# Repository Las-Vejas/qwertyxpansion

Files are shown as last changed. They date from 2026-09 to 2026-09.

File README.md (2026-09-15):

# qwertyxpansion

This is a keyboard for the [Hackxpansion console](https://github.com/hackclub/hackxpansion). It features a qwerty keyboard, with 4 modifier keys and an LED. The switches are SPST.

I will be making the 3d case later on, as it's very hard to make correctly without the actual PCB.

## Images
|||
|---|---|
|||

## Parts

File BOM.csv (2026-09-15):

Reference | Price | Price | Value | LCSC Part #
D1,D2,D3,D4,D5,D6,D7,D8,D9,D10,D11,D12,D13,D14,D15,D16,D17,D18,D19,D20,D21,D22,D23,D24,D25,D26,D27,D28,D29,D30,D31,D32,D33 | 1.44 $US | 33 | D_Small | C28646371
D34 | 0.69 $US | 1 | LED | C20608782
J1,J2 | 0.00 $US | 2
R1 | 0.19 $US | 1 | 75K | C2909383
R2 | 0.15 $US | 1 | 1K | C140197
R3 | 0.21 $US | 1 | 300 | C25102
SW1,SW2,SW3,SW4,SW5,SW6,SW7,SW8,SW9,SW10,SW11,SW12,SW13,SW14,SW15,SW16,SW17,SW18,SW19,SW20,SW21,SW22,SW23,SW24,SW25,SW26,SW27,SW28,SW29,SW30,SW31,SW32,SW33 | 2.02 $US | 33 | SW_Push_45deg | C720477
PCB | 4.00 $US | 5
Stencil | 3.07 $US | 1
TOTAL | 11.77 $US

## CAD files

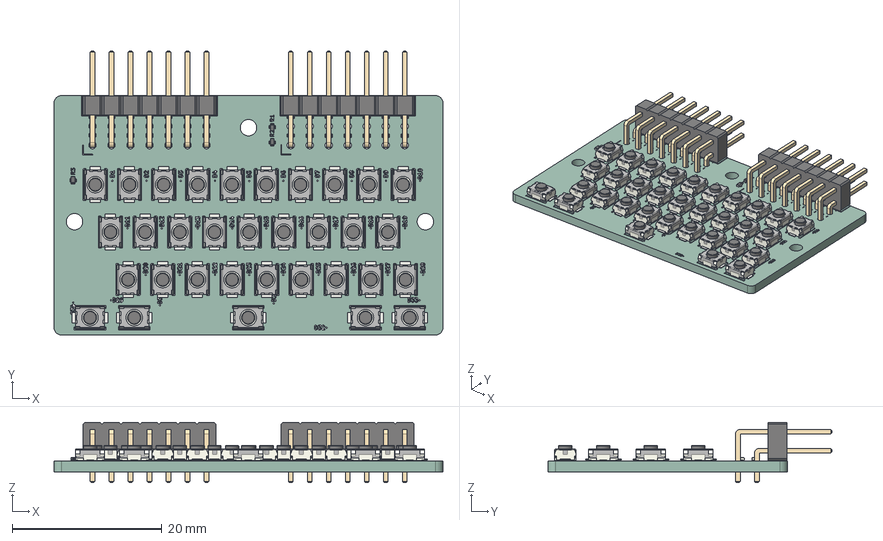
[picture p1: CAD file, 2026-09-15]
3d/qwertyxpansionPCB.step
52.0 x 38.0 x 8.08 mm
SW_Push_SPST_NO_Alps_SKRK x 33
R_0402_1005Metric x 3
PinHeader_2x07_P254mm_Horizontal x 2
keeb_silkscreen x 2
keeb_PCB

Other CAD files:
3d/qwertyxpansionCASE.f3z

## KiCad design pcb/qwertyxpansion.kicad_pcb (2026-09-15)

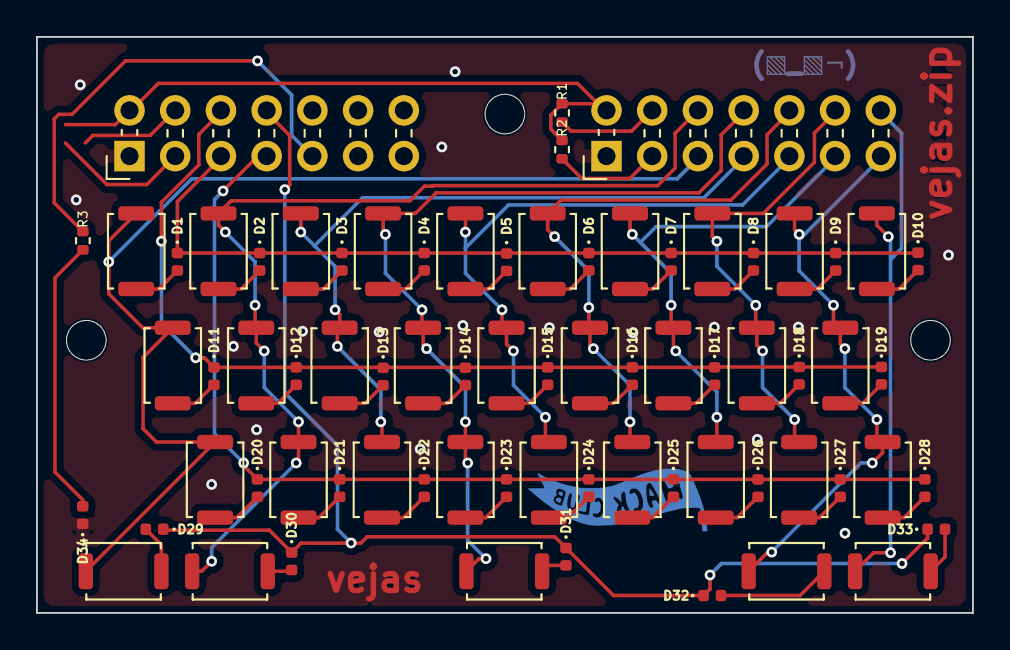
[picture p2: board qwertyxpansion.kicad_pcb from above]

Board: 2 copper layers, 52.0 x 32.0 mm, 72 parts (0 on the bottom side), 53 nets.

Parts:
D1, D2, D3, D4, D5, D6, D7, D8, D9, D10, D11, D12, D13, D14, D15, D16, D17, D18, D19, D20, D21, D22, D23, D24, D25, D26, D27, D28, D29, D30, D31, D32, D33: D_Small; D_0402_1005Metric
D34: LED; D_0402_1005Metric
J1, J2: PinHeader_2x07_P2.54mm_Horizontal
R1: 75K; R_0402_1005Metric
R2: 1K; R_0402_1005Metric
R3: 300; R_0402_1005Metric
SW1: Q; SW_Push_SPST_NO_Alps_SKRK
SW2: W; SW_Push_SPST_NO_Alps_SKRK
SW3: E; SW_Push_SPST_NO_Alps_SKRK
SW4: R; SW_Push_SPST_NO_Alps_SKRK
SW5: T; SW_Push_SPST_NO_Alps_SKRK
SW6: Y; SW_Push_SPST_NO_Alps_SKRK
SW7: U; SW_Push_SPST_NO_Alps_SKRK
SW8: I; SW_Push_SPST_NO_Alps_SKRK
SW9: O; SW_Push_SPST_NO_Alps_SKRK
SW10: P; SW_Push_SPST_NO_Alps_SKRK
SW11: A; SW_Push_SPST_NO_Alps_SKRK
SW12: S; SW_Push_SPST_NO_Alps_SKRK
SW13: D; SW_Push_SPST_NO_Alps_SKRK
SW14: F; SW_Push_SPST_NO_Alps_SKRK
SW15: G; SW_Push_SPST_NO_Alps_SKRK
SW16: H; SW_Push_SPST_NO_Alps_SKRK
SW17: J; SW_Push_SPST_NO_Alps_SKRK
SW18: K; SW_Push_SPST_NO_Alps_SKRK
SW19: L; SW_Push_SPST_NO_Alps_SKRK
SW20: Z; SW_Push_SPST_NO_Alps_SKRK
SW21: X; SW_Push_SPST_NO_Alps_SKRK
SW22: C; SW_Push_SPST_NO_Alps_SKRK
SW23: V; SW_Push_SPST_NO_Alps_SKRK
SW24: B; SW_Push_SPST_NO_Alps_SKRK
SW25: N; SW_Push_SPST_NO_Alps_SKRK
SW26: M; SW_Push_SPST_NO_Alps_SKRK
SW27: ,; SW_Push_SPST_NO_Alps_SKRK
SW28: .; SW_Push_SPST_NO_Alps_SKRK
SW29, SW30, SW31, SW32, SW33: SW_Push_45deg; SW_Push_SPST_NO_Alps_SKRK

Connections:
+3V3: J1.2 (3V3), J2.2 (3V3), R1.1, R2.1
/COL1: J1.5 (GPIO0), SW1.1, SW11.1, SW20.1, SW29.1
/COL2: J1.6 (GPIO1), SW2.1, SW12.1, SW21.1, SW30.1
/COL3: J1.7 (GPI02), SW3.1, SW13.1, SW22.1
/COL4: J1.8 (GPIO3), SW4.1, SW14.1, SW23.1, SW31.1
/COL5: J1.9 (GPIO4), SW5.1, SW15.1, SW24.1
/COL6: J1.10 (GPIO5), SW6.1, SW16.1, SW25.1
/COL7: J1.11 (GPIO6), SW7.1, SW17.1, SW26.1
/COL8: J1.12 (GPIO7), SW8.1, SW18.1, SW27.1
/COL9: J1.13 (GPIO8), SW9.1, SW19.1, SW28.1, SW32.1
/COL10: J1.14 (GPIO9), SW10.1, SW33.1
/ROW1: D1.1 (K), D2.1 (K), D3.1 (K), D4.1 (K), D5.1 (K), D6.1 (K), D7.1 (K), D8.1 (K), D9.1 (K), D10.1 (K), J2.5 (GPIO0)
/ROW2: D11.1 (K), D12.1 (K), D13.1 (K), D14.1 (K), D15.1 (K), D16.1 (K), D17.1 (K), D18.1 (K), D19.1 (K), J2.6 (GPIO1)
/ROW3: D20.1 (K), D21.1 (K), D22.1 (K), D23.1 (K), D24.1 (K), D25.1 (K), D26.1 (K), D27.1 (K), D28.1 (K), J2.7 (GPI02)
/ROW4: D29.1 (K), D30.1 (K), D31.1 (K), D32.1 (K), D33.1 (K), J2.8 (GPIO3)
GND: D34.1 (K), J1.1 (GND), J2.1 (GND)
unnamed: D1.2 (A), SW1.2
unnamed: D2.2 (A), SW2.2
unnamed: D3.2 (A), SW3.2
unnamed: D4.2 (A), SW4.2
unnamed: D5.2 (A), SW5.2
unnamed: D6.2 (A), SW6.2
unnamed: D7.2 (A), SW7.2
unnamed: D8.2 (A), SW8.2
unnamed: D9.2 (A), SW9.2
unnamed: D10.2 (A), SW10.2
unnamed: D11.2 (A), SW11.2
unnamed: D12.2 (A), SW12.2
unnamed: D13.2 (A), SW13.2
unnamed: D14.2 (A), SW14.2
unnamed: D15.2 (A), SW15.2
unnamed: D16.2 (A), SW16.2
unnamed: D17.2 (A), SW17.2
unnamed: D18.2 (A), SW18.2
unnamed: D19.2 (A), SW19.2
unnamed: D20.2 (A), SW20.2
unnamed: D21.2 (A), SW21.2
unnamed: D22.2 (A), SW22.2
unnamed: D23.2 (A), SW23.2
unnamed: D24.2 (A), SW24.2
unnamed: D25.2 (A), SW25.2
unnamed: D26.2 (A), SW26.2
unnamed: D27.2 (A), SW27.2
unnamed: D28.2 (A), SW28.2
unnamed: D29.2 (A), SW29.2
unnamed: D30.2 (A), SW30.2
unnamed: D31.2 (A), SW31.2
unnamed: D32.2 (A), SW32.2
unnamed: D33.2 (A), SW33.2
unnamed: D34.2 (A), R3.2
unnamed: J1.3 (MD0), R2.2
unnamed: J1.4 (MD1), R1.2
unnamed: J2.9 (GPIO4), R3.1

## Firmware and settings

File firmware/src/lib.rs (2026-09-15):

#![no_std]

extern crate alloc;

use alloc::boxed::Box;
use core::future::Future;
use core::pin::Pin;

use xpanse_api::{
    bus::allocator::BusAllocator,
    driver::{DriverError, DriverMeta, DualSlotDriver},
    gpio_bank::{BankPins, GpioBank},
    interfaces::leds::{Generic, pin_led},
    metadata::{ModuleDetectResistor, ModuleID, ModuleSlot},
    registry::Registry,
    reexports::{
        embassy_futures::select::select_array,
        embassy_rp::{
            Peri,
            gpio::{AnyPin, Input, Level, Output, Pull},
        },
        embassy_time::Timer,
    },
};

/// ROW1..ROW4, on GPIO0..GPIO3 of the left connector (J2).
const ROWS: usize = 4;
/// COL1..COL10, on GPIO0..GPIO9 of the right connector (J1).
const COLS: usize = 10;

/// Time for a column to follow its row after the row is switched.
const SETTLE_US: u64 = 10;
const SCAN_INTERVAL_MS: u64 = 1;
/// A matrix change is accepted once it reads the same for this many scans.
const DEBOUNCE_SCANS: u32 = 5;

/// A physical key on the module.
#[derive(Debug, Clone, Copy, PartialEq, Eq)]
pub enum Key {
    Q,
    W,
    E,
    R,
    T,
    Y,
    U,
    I,
    O,
    P,
    A,
    S,
    D,
    F,
    G,
    H,
    J,
    K,
    L,
    Z,
    X,
    C,
    V,
    B,
    N,
    M,
    Comma,
    Period,
    Space,
    /// Bottom row, far left (SW29).
    Mod1,
    /// Bottom row, left of the space bar (SW30).
    Mod2,
    /// Bottom row, right of the space bar (SW32).
    Mod3,
    /// Bottom row, far right (SW33).
    Mod4,
}

impl Key {
    /// The character the key types without modifiers, or `None` for modifiers.
    pub const fn as_char(self) -> Option<char> {
        Some(match self {
            Key::Q => 'q',
            Key::W => 'w',
            Key::E => 'e',
            Key::R => 'r',
            Key::T => 't',
            Key::Y => 'y',
            Key::U => 'u',
            Key::I => 'i',
            Key::O => 'o',
            Key::P => 'p',
            Key::A => 'a',
            Key::S => 's',
            Key::D => 'd',
            Key::F => 'f',
            Key::G => 'g',
            Key::H => 'h',
            Key::J => 'j',
            Key::K => 'k',
            Key::L => 'l',
            Key::Z => 'z',
            Key::X => 'x',
            Key::C => 'c',
            Key::V => 'v',
            Key::B => 'b',
            Key::N => 'n',
            Key::M => 'm',
            Key::Comma => ',',
            Key::Period => '.',
            Key::Space => ' ',
            Key::Mod1 | Key::Mod2 | Key::Mod3 | Key::Mod4 => return None,
        })
    }

    /// Bit of this key in a matrix state word.
    fn bit(self) -> u64 {
        for (index, key) in KEYMAP.iter().flatten().enumerate() {
            if *key == Some(self) {
                return 1 << index;
            }
        }
        unreachable!("every key is in the keymap")
    }
}

/// Key at each `[row][column]` of the matrix, taken from the PCB netlist.
/// Positions with no switch are `None`.
const KEYMAP: [[Option<Key>; COLS]; ROWS] = {
    use Key::*;
    [
        [Some(Q), Some(W), Some(E), Some(R), Some(T), Some(Y), Some(U), Some(I), Some(O), Some(P)],
        [Some(A), Some(S), Some(D), Some(F), Some(G), Some(H), Some(J), Some(K), Some(L), None],
        [Some(Z), Some(X), Some(C), Some(V), Some(B), Some(N), Some(M), Some(Comma), Some(Period), None],
        [Some(Mod1), Some(Mod2), None, Some(Space), None, None, None, None, Some(Mod3), Some(Mod4)],
    ]
};

/// Bits of the matrix positions that have a switch.
const KEY_MASK: u64 = {
    let mut mask = 0;
    let mut index = 0;
    while index < ROWS * COLS {
        if KEYMAP[index / COLS][index % COLS].is_some() {
            mask |= 1 << index;
        }
        index += 1;
    }
    mask
};

/// A debounced key press or release.
#[derive(Debug, Clone, Copy, PartialEq, Eq)]
pub struct KeyEvent {
    pub key: Key,
    pub pressed: bool,
}

/// Async interface to the keyboard.
///
/// Apps lease it from the registry as `Box<dyn Keyboard>`.
pub trait Keyboard: Send {
    /// Wait for the next key press or release.
    fn next_event<'a>(&'a mut self) -> Pin<Box<dyn Future<Output = KeyEvent> + Send + 'a>>;

    /// Returns `true` if `key` is held, as of the last event returned by
    /// [`Keyboard::next_event`].
    fn is_pressed(&self, key: Key) -> bool;
}

/// 4x10 matrix with diodes from column to row: a row is selected by driving it
/// low, and a pressed key on that row pulls its column low through the diode.
struct KeyMatrix {
    rows: [Output<'static>; ROWS],
    cols: [Input<'static>; COLS],
    /// Debounced matrix state, one bit per position.
    debounced: u64,
    /// State already delivered to the app as events.
    reported: u64,
}
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
